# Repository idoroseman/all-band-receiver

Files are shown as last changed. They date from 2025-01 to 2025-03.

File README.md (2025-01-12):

Dear All-Band Receiver Enthusiasts,
-----------------------------------

First and foremost, I want to express my heartfelt gratitude for the overwhelming response to my recent article on the all-band receiver. Your interest and enthusiasm have truly exceeded my expectations. When I published the article, I had no idea it would garner such a high turnout of comments and support.

Unfortunately, I wasn't expecting such a turnout, as I only had a couple of spare PCBs on hand. However, I have some great news! I’ll be producing more boards, which will incorporate the future enhancements described in [the article](https://idoroseman.com/how-to-use-an-all-band-receiver-to-listen-to-airplane-pilot-communications-with-ground-controllers/) and will be available for purchase online in a few weeks. 
You’ll have the option to buy the PCB on its own or as part of a kit that includes a 3D-printed enclosure.

For those who prefer a DIY approach, I’ve uploaded all the necessary files to a GitHub repository, so you can get started on your own build. You can find the repository [here](https://github.com/idoroseman/all-band-receiver).

I also want to take a moment to thank the [original authors](https://techlib.com/electronics/allband.htm) who made this project possible: Charles Wenzel and Paul Beaumont (G7VAK). Their foundational work was instrumental in inspiring this project.

If you have any comments, suggestions, or ideas, please don’t hesitate to reach out. I’d love to hear your feedback and thoughts. You can email me at ido.roseman@gmail.com.

Thank you once again for your incredible support. Stay tuned for updates on the boards’ availability and other exciting developments!

Best regards,
Ido Roseman
[idoroseman.com](https://idoroseman.com/)

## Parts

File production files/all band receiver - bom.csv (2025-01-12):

Reference | Value | Datasheet | Footprint | Qty | DNP
BT1 | Keystone 1294 | https://www.keyelco.com/userAssets/file/m70p37.pdf | easyeda2kicad:keystone 1294 | 1
C1 | 100pF | ~ | Capacitor_SMD:C_0805_2012Metric_Pad1.18x1.45mm_HandSolder | 1
C2,C3 | 1nF | ~ | Capacitor_SMD:C_0805_2012Metric_Pad1.18x1.45mm_HandSolder | 2
C4 | 100nF | ~ | Capacitor_SMD:C_0805_2012Metric_Pad1.18x1.45mm_HandSolder | 1
C5 | 4.7nF | ~ | Capacitor_SMD:C_0805_2012Metric_Pad1.18x1.45mm_HandSolder | 1
C6 | 47nF | ~ | Capacitor_SMD:C_0805_2012Metric_Pad1.18x1.45mm_HandSolder | 1
C7 | 220uF | ~ | Capacitor_SMD:CP_Elec_6.3x5.4 | 1
C8 | 1uF | ~ | Capacitor_SMD:CP_Elec_4x5.3 | 1
C9 | 10uF | ~ | Capacitor_SMD:C_0805_2012Metric_Pad1.18x1.45mm_HandSolder | 1
D1 | BAT41 | ~ | Diode_SMD:D_SOD-123 | 1
FB1 | FerriteBead | ~ | Inductor_SMD:L_0805_2012Metric_Pad1.15x1.40mm_HandSolder | 1
J1 | AudioJack3_SwitchT | ~ | Connector_Audio:Jack_3.5mm_CUI_SJ-3524-SMT_Horizontal | 1
J2 | Conn_01x01_Socket | ~ | Connector_Wire:SolderWire-0.5sqmm_1x01_D0.9mm_OD2.1mm | 1
J3 | Conn_01x02_Socket | ~ | Connector_PinSocket_2.54mm:PinSocket_1x02_P2.54mm_Vertical | 1 | DNP
L1 | 270nH | ~ | Inductor_SMD:L_0805_2012Metric_Pad1.15x1.40mm_HandSolder | 1
Q1 | 2N4401 | ~ | Package_TO_SOT_SMD:SOT-23 | 1
R1 | ~ | https://www.lcsc.com/datasheet/lcsc_datasheet_2311142111_TT-Electronics-P091S-EC20BR50K_C17372788.pdf | easyeda2kicad:P091S-QC15BR | 1
R2,R7 | 10K | ~ | Resistor_SMD:R_0805_2012Metric_Pad1.20x1.40mm_HandSolder | 2
R3,R4 | 10M | ~ | Resistor_SMD:R_0805_2012Metric_Pad1.20x1.40mm_HandSolder | 2
R5 | 100R | ~ | Resistor_SMD:R_0805_2012Metric_Pad1.20x1.40mm_HandSolder | 1
R6 | 100K | ~ | Resistor_SMD:R_0805_2012Metric_Pad1.20x1.40mm_HandSolder | 1
R8 | 10R | ~ | Resistor_SMD:R_0805_2012Metric_Pad1.20x1.40mm_HandSolder | 1
R9 | 1K2 | ~ | Resistor_SMD:R_0805_2012Metric_Pad1.20x1.40mm_HandSolder | 1
TP1,TP2,TP3,TP4 | TestPoint | ~ | -- mixed values -- | 4
U1 | LM386 | http://www.ti.com/lit/ds/symlink/lm386.pdf | Package_SO:SOIC-8_3.9x4.9mm_P1.27mm | 1

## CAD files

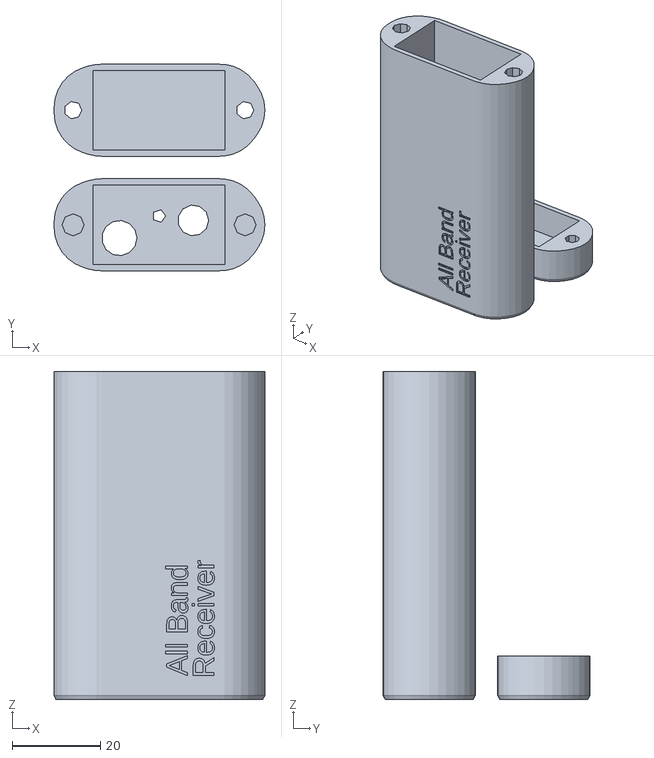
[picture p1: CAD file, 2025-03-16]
mechanical/all band receiver box.stl
47.8 x 46.9 x 74.4

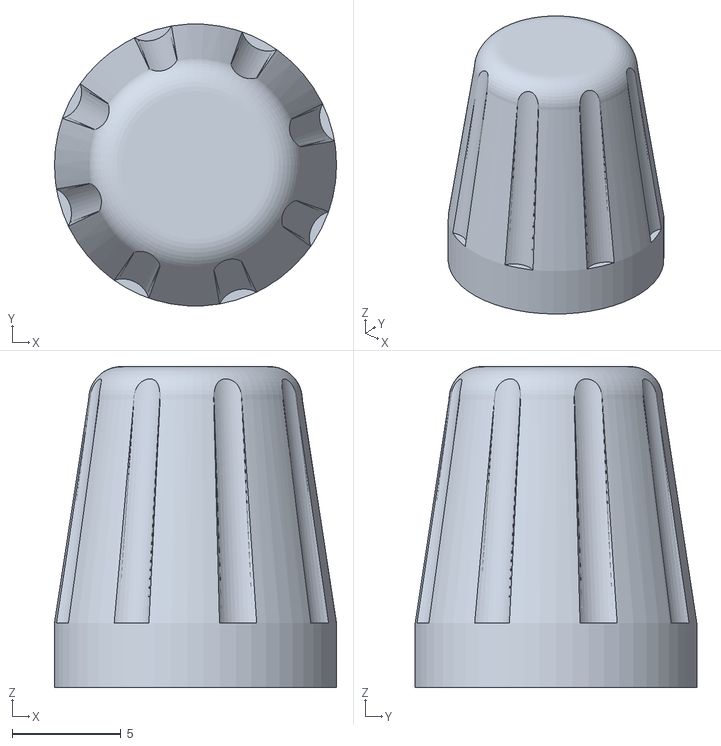
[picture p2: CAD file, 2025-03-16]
mechanical/pot_knob-6mm-clear.stl
13.0 x 13.0 x 14.8

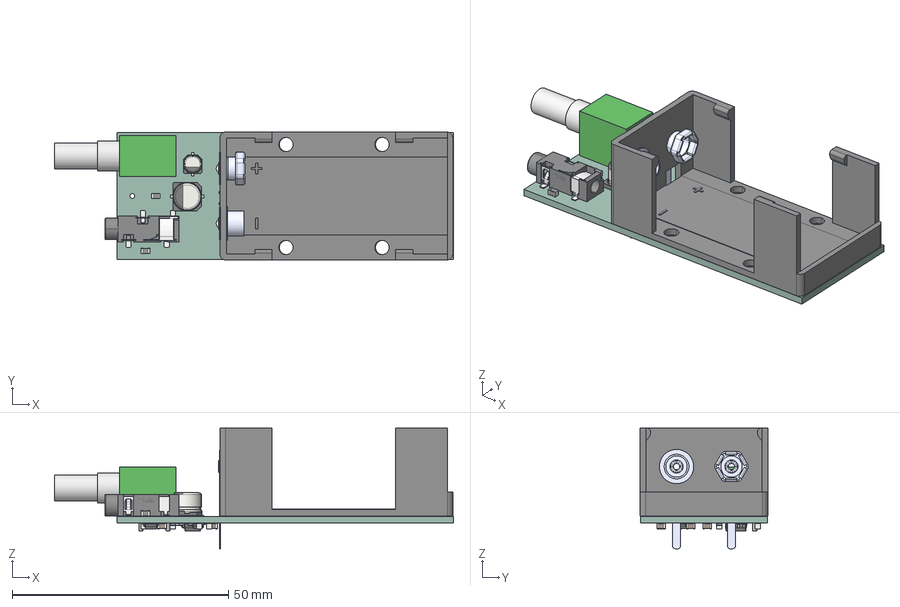
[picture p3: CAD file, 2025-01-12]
mechanical/all band receiver.step
92.3 x 29.6 x 27.9 mm
CP_Elec_4x53
L_0805_2012Metric x 2
CP_Elec_63x54
AUDIO-SMD_L11.8-W6.0-H5.0-4P
R_0805_2012Metric x 8
C_0805_2012Metric x 7
SOT_23
D_SOD_123
SOIC_8_39x49mm_P127mm
all band receiver_PCB

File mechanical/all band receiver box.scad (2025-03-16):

w=1.5;

// cavity
cx = 30;
cy = 18;
cz = 73;

module body(h){
    difference(){
        translate([2,0,0]) minkowski(){
            translate([1,1,1]) union(){
                cube([cx-2*w, cy-2+2*w, h]);
                for (i=[0,cx-2*w])
                    translate([i, (cy-2+2*w)/2, 0]) cylinder(h=h, d=cy-2+2*w);
            }
            sphere(d=2);
        }
    // cavity
    translate([w, w, w]) cube([cx, cy, h]);

    // top
    translate([-cy, 0, h]) cube([cx+2*cy+2*w, cy+2*w, 5]);
    }        
}

module batt_9v(){
    cube([26.5, 17.5, 46]);

}

// main
difference(){
    body(h=cz+w);
    
    // volume knob
    translate([w+6, w+6, 0]) cylinder(h=w+1, d=7+1); 

    // phones jack
    translate([w+6+16.75, w+10, 0]) cylinder(h=w+1, d=5+2); 
 
    
    // cover inserts
    for (i=[-2*w, cx+2*w+2*w])
        translate([i, (cy+2*w)/2, cz-10]) cylinder(d=5, h=20);
    
    // text
    // translate([10, 0.5, cz-21]) rotate([90, -90, 0]) linear_extrude(1) text("4X6UB", size=5);
    translate([cx-7, 0.5, 5.5]) rotate([90, -90, 0]) linear_extrude(1) text("All Band", size=5);
    translate([cx-1, 0.5, 5]) rotate([90, -90, 0]) linear_extrude(1) text("Receiver", size=5);
    
}

// cover
translate([0, cy+2*w+5, 0]) difference() {
    body(10);

    // cover screws
    for (i=[-2*w, cx+2*w+2*w]){
        translate([i, (cy+2*w)/2, 0]) cylinder(d=3+1, h=20);
        translate([i, (cy+2*w)/2, 0]) cylinder(d=6+1, h=5);
    }
}

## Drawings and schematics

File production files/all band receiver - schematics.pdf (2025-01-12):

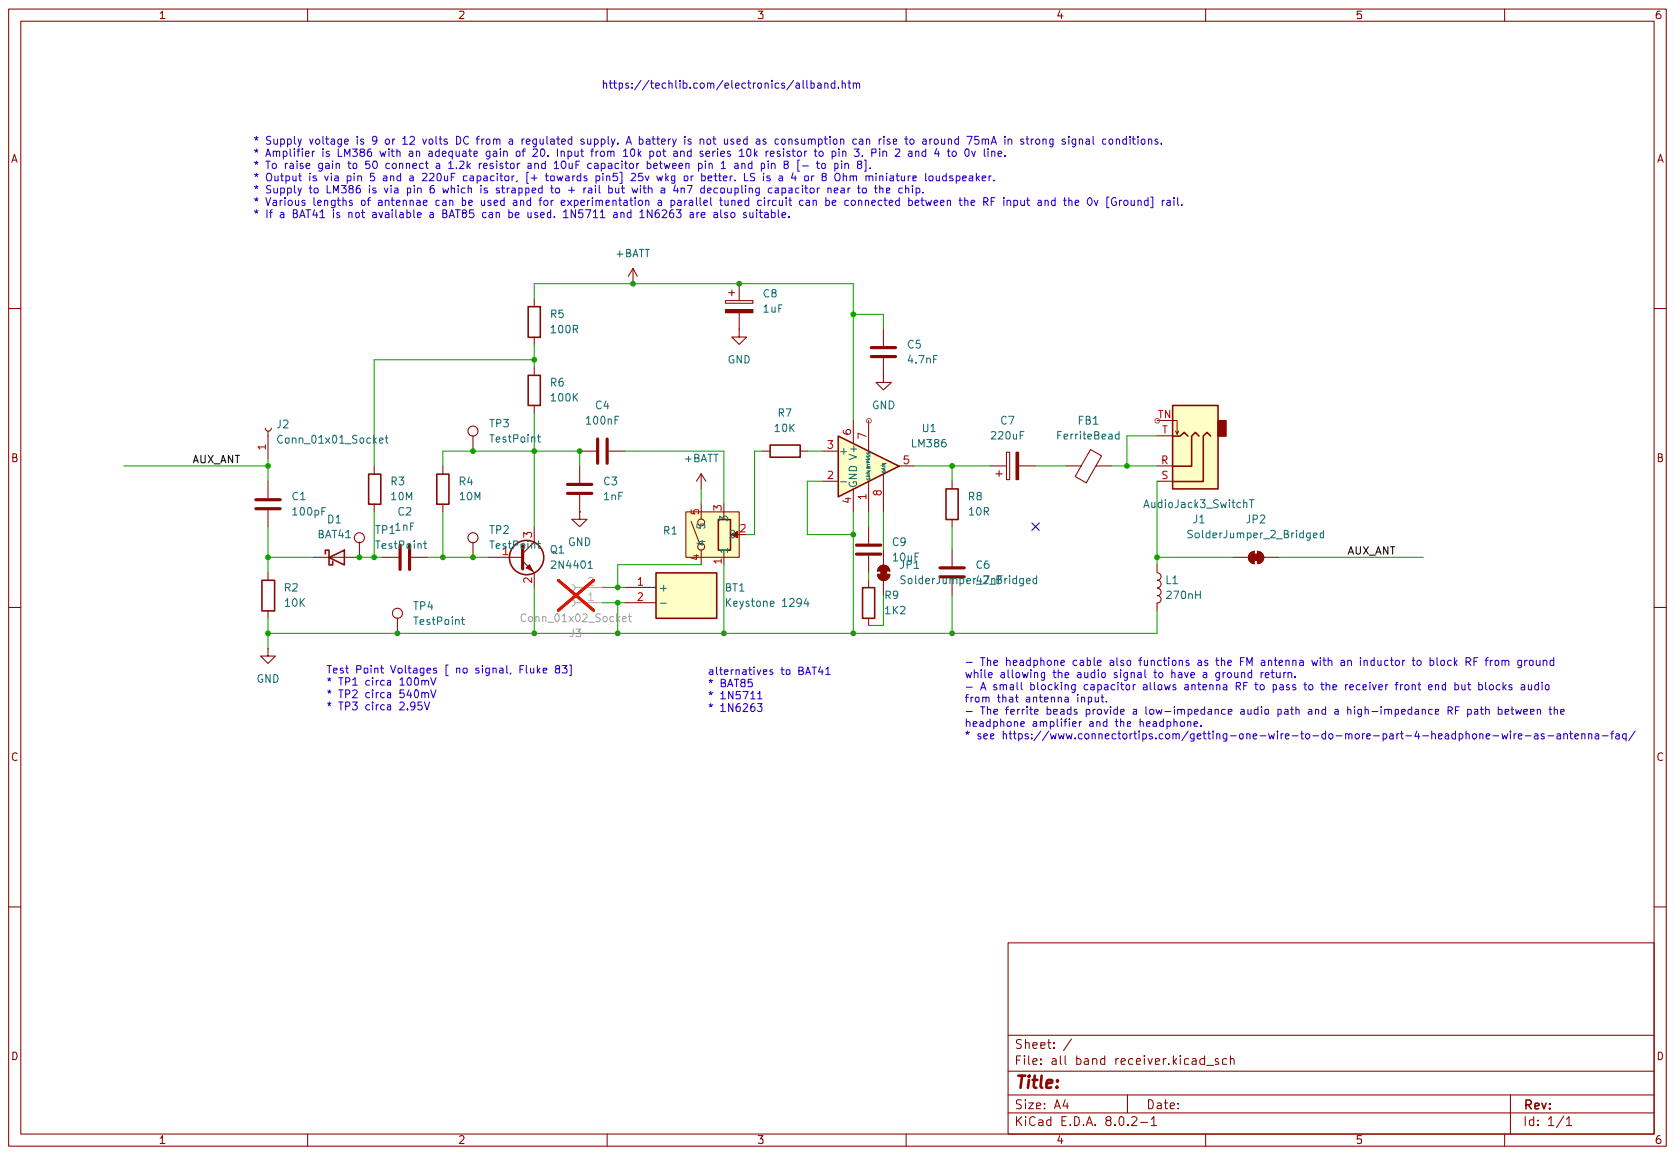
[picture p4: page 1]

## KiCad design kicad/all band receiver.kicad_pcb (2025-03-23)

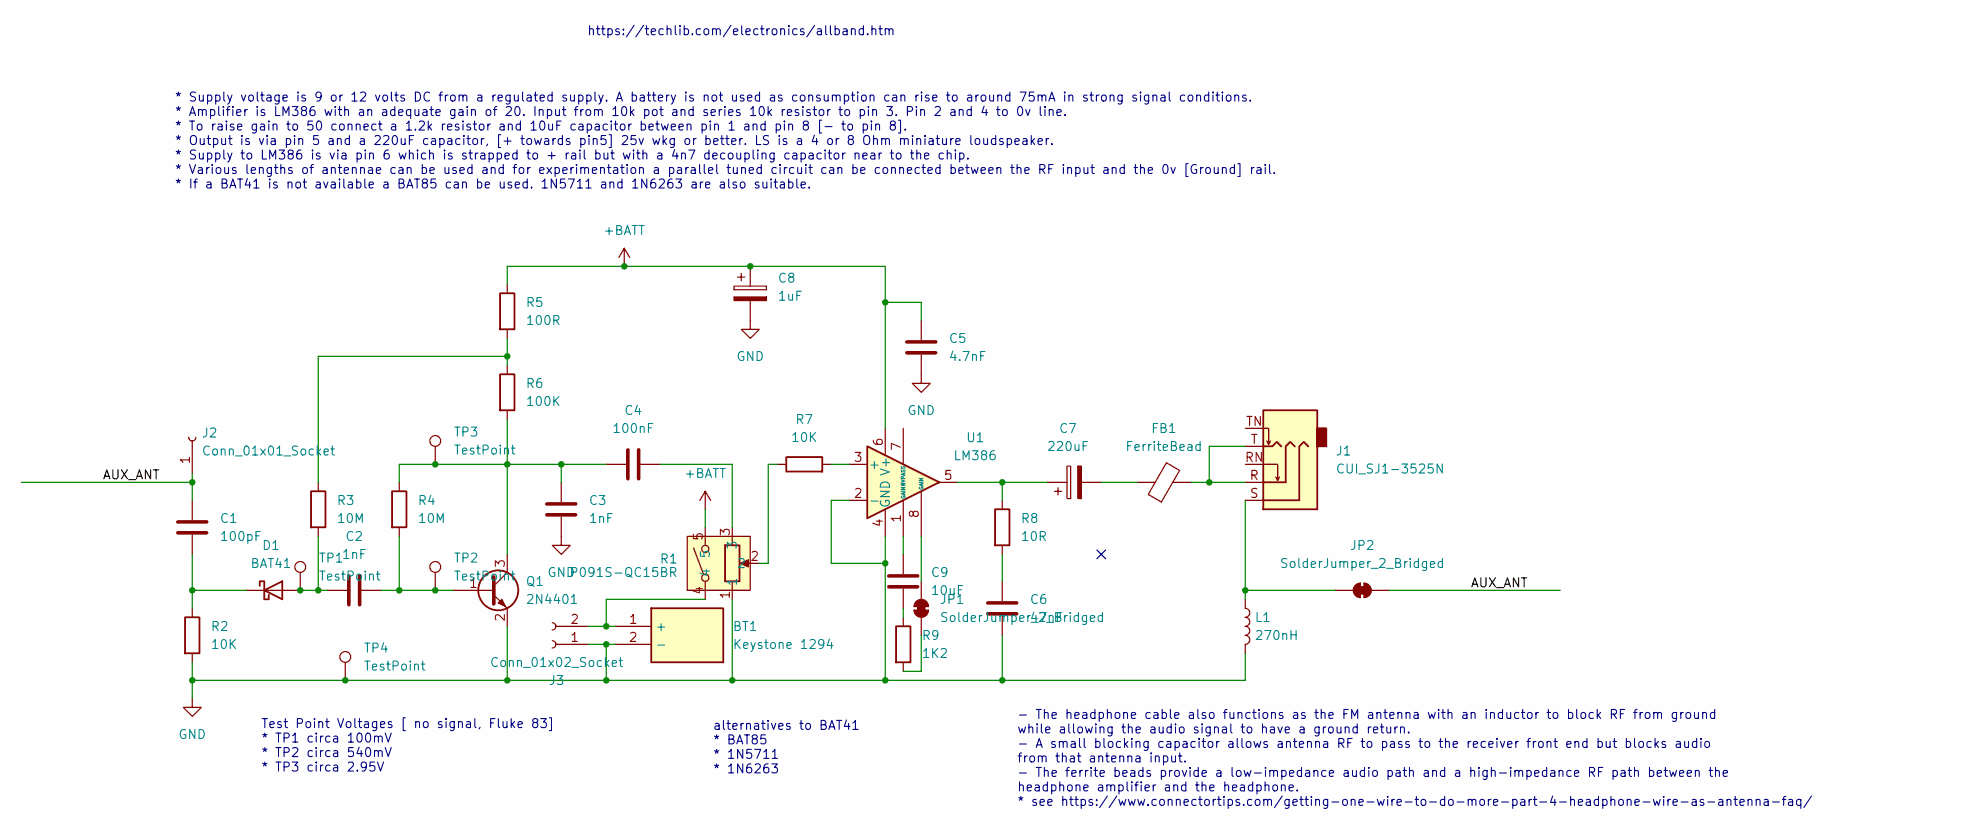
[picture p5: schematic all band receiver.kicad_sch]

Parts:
BT1: Keystone 1294; keystone 1294; Mouser Part Number 534-1294
C1: 100pF; C_0805_2012Metric_Pad1.18x1.45mm_HandSolder; Mouser Part Number 80-C0805C101K1HACTU; DigiKey Part Number 399-C0805C101J5GACTUCT-ND
C2, C3: 1nF; C_0805_2012Metric_Pad1.18x1.45mm_HandSolder; Mouser Part Number 187-CL21B102KBANNND; DigiKey Part Number 399-C0805C102K5RACTUCT-ND
C4: 100nF; C_0805_2012Metric_Pad1.18x1.45mm_HandSolder; Mouser Part Number 187-CL21B104MACNNNC; DigiKey Part Number 311-1140-1-ND
C5: 4.7nF; C_0805_2012Metric_Pad1.18x1.45mm_HandSolder; Mouser Part Number 791-0805N472J500CT; DigiKey Part Number 311-1133-1-ND
C6: 47nF; C_0805_2012Metric_Pad1.18x1.45mm_HandSolder; Mouser Part Number 791-0805B473J500CT; DigiKey Part Number 399-C0805C473K5RACTUCT-ND
C7: 220uF; CP_Elec_6.3x5.4; Mouser Part Number 140-VZL221M1CTR-0607; DigiKey Part Number 478-APA0608221M010RCT-ND
C8: 1uF; CP_Elec_4x5.3; Mouser Part Number 710-865060640001; DigiKey Part Number 732-6401-1-ND
C9: 10uF; C_0805_2012Metric_Pad1.18x1.45mm_HandSolder; Mouser Part Number 187-CL21A106KQFNFNE; DigiKey Part Number 587-1300-1-ND
D1: BAT41; D_SOD-123; Mouser Part Number 511-BAT41ZFILM; DigiKey Part Number 497-5558-1-ND
FB1: FerriteBead; L_0805_2012Metric_Pad1.15x1.40mm_HandSolder; Mouser Part Number 70-ILBB0805ER110V; DigiKey Part Number MH2029-070YCT-ND
J1: CUI_SJ1-3525N; Jack_3.5mm_CUI_SJ1-3525N_Horizontal; Mouser Part Number 490-SJ1-3525NG-GR; DigiKey Part Number SJ1-3525NG
J2: Conn_01x01_Socket; PinHeader_1x01_P2.54mm_Horizontal
J3: Conn_01x02_Socket; PinSocket_1x02_P2.54mm_Vertical
JP1, JP2: SolderJumper_2_Bridged; SolderJumper-2_P1.3mm_Bridged_RoundedPad1.0x1.5mm
L1: 270nH; L_0805_2012Metric_Pad1.15x1.40mm_HandSolder; Mouser Part Number 70-IMC0805ERR27J01; DigiKey Part Number 118-CE201210-R27JCT-ND
Q1: 2N4401; SOT-23; Mouser Part Number 637-MMBT4401; DigiKey Part Number 4786-MMBT4401CT-ND
R1: P091S-QC15BR; Mouser Part Number 858-P091SFC20BR10K; DigiKey Part Number 987-1284-ND
R2, R7: 10K; R_0805_2012Metric_Pad1.20x1.40mm_HandSolder; Mouser Part Number 71-CRCW0805-10K-E3; DigiKey Part Number P10KACT-ND
R3, R4: 10M; R_0805_2012Metric_Pad1.20x1.40mm_HandSolder; Mouser Part Number 603-RC0805FR-0710ML; DigiKey Part Number P10MACT-ND
R5: 100R; R_0805_2012Metric_Pad1.20x1.40mm_HandSolder; Mouser Part Number 603-AC0805FR-7W100RL; DigiKey Part Number P100ACT-ND
R6: 100K; R_0805_2012Metric_Pad1.20x1.40mm_HandSolder; Mouser Part Number 652-CR0805FX-1003ELF; DigiKey Part Number P100KACT-ND
R8: 10R; R_0805_2012Metric_Pad1.20x1.40mm_HandSolder; Mouser Part Number 603-AC0805JR-0710RL; DigiKey Part Number RMCF0805JT10R0CT-ND
R9: 1K2; R_0805_2012Metric_Pad1.20x1.40mm_HandSolder; Mouser Part Number 652-CR0805FX-1201ELF; DigiKey Part Number A126346CT-ND
TP1, TP2, TP3: TestPoint; TestPoint_Pad_D1.5mm
TP4: TestPoint; TestPoint_Pad_2.0x2.0mm
U1: LM386; SOIC-8_3.9x4.9mm_P1.27mm; Mouser Part Number 926-LM386MX-1/NOPB; DigiKey Part Number LM386MX-1/NOPBCT-ND

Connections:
+BATT: C5.2, C8.1, R1.5, R5.1, U1.6 (V+)
/AUX_ANT: C1.1, J2.1, JP2.1 (A)
GND: BT1.2 (-), C3.2, C5.1, C6.1, C8.2, J3.1, L1.2, Q1.2 (E), R1.1, R2.2, TP4.1, U1.2 (-), U1.4 (GND)
unnamed: BT1.1 (+), J3.2, R1.4
unnamed: C4.2, R1.3
unnamed: C6.2, R8.2
unnamed: C7.1, R8.1, U1.5
unnamed: C7.2, FB1.1
unnamed: C9.1, R9.1
unnamed: C9.2, U1.1 (GAIN)
unnamed: C2.1, D1.2 (A), R3.2, TP1.1
unnamed: C1.2, D1.1 (K), R2.1
unnamed: FB1.2, J1.R, J1.T
unnamed: JP1.1 (A), R9.2
unnamed: JP1.2 (B), U1.8 (GAIN)
unnamed: J1.S, JP2.2 (B), L1.1
unnamed: C2.2, Q1.1 (B), R4.2, TP2.1
unnamed: C3.1, C4.1, Q1.3 (C), R4.1, R6.2, TP3.1
unnamed: R1.2, R7.1
unnamed: R3.1, R5.2, R6.1
unnamed: R7.2, U1.3 (+)

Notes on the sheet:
 alternatives to BAT41 * BAT85 * 1N5711 * 1N6263
* Supply voltage is 9 or 12 volts DC from a regulated supply. A battery is not used as consumption can rise to around 75mA in strong signal conditions. * Amplifier is LM386 with an adequate gain of 20. Input from 10k pot and series 10k resistor to pin 3. Pin 2 and 4 to 0v line. * To raise gain to 5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
 Test Point Voltages [ no signal, Fluke 83] * TP1 circa 100mV * TP2 circa 540mV * TP3 circa 2.95V
https://techlib.com/electronics/allband.htm
- The headphone cable also functions as the FM antenna with an inductor to block RF from ground while allowing the audio signal to have a ground return. - A small blocking capacitor allows antenna RF to pass to the receiver front end but blocks audio from that antenna input. - The ferrite beads pro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

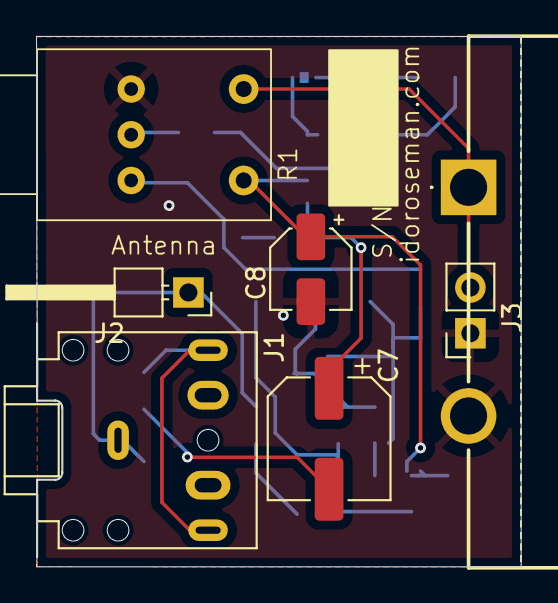
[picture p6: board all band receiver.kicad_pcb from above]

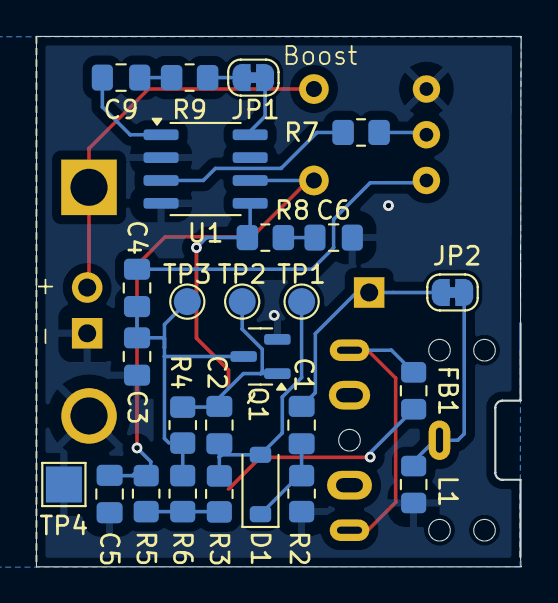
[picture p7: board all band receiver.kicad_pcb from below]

Board: 2 copper layers, 26.9 x 29.5 mm, 33 parts (26 on the bottom side), 21 nets.

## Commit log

2025-01-12 moved (almost) all smt components to bottom side so manufacturing is cheaper. chanded audio connector on upper side to thruhole for easy soldering
    [all band receiver.kicad_pcb, all band receiver.kicad_sch]
2025-03-23 increased thermal relief for easier soldering
    [all band receiver.kicad_pcb]
